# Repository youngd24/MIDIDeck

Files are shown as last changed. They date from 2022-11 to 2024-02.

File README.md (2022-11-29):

# The MIDI Deck

What is it? an Arduino Pro Micro MIDI controller, connected via USB, that can send MIDI messages to a host on button press. The idea is to automate apps on the host, in my primary use case, OBS. Press button, things happen.

The design is as dead simple as possible so it's easy to build, total cost is under $20 (likely less).

Full docs [here](https://youngd24.github.io/MIDIDeck/)

A YouTube video that describes this is [here](https://youtu.be/XT2bshyCDlI)

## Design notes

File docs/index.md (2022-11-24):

# MIDI Deck

What is it? an Arduino Pro Micro MIDI controller, connected via USB, that can send MIDI messages to a host on button press. The idea is to automate apps on the host, in my primary use case, OBS. Press button, things happen.

The design is as dead simple as possible so it's easy to build, total cost is under $20 (likely less).

MIDIDeck_Image

## Why?

There were 2 main drivers I had for building this, the first is when I'm recording for YouTube videos. I use OBS with several cameras and other inputs and rather than flipping between them in editing I switch while recording. Why? I hate editing and this saves time there.

Second is for streaming, the keyboad combos I ended up using in OBS were awkward to use and I was always forgetting them. There's a reason the StreamDeck exists, this serves the same function.

## Goals

For the initial version, I had the following objectives:

* All command comms use MIDI (rather than HID)
* Prefer an Arduino platform
* Be as simple as possible to build
* Low cost
* Use PlatformIO to build

### MIDI

So why MIDI and not HID? Well, mainly because I have some other projects that I want to use MIDI on an Arduino for, this was the chance to have a super simple project to learn how to do it. My learning process tends to be additive and cumulative, I start with simple ideas, learn it thoroughly, then grow and learn more.

### Arduino

Why Arduino and not a, say, ESP32 or even a Raspberry Pi? The Pi could certainly do this but as of this writing, late 2022, they're still difficult to find and tend to be costly due to the [chip chortage](https://www.youtube.com/watch?v=vGjQcPUfBdM).

The specific Arduino I chose was the [Pro Micro](https://docs.arduino.cc/hardware/micro), it has sufficient pins and runs the ATmega32u4 processor with native USB support. It's that processor that enables the MIDI goal to be met. Note that this board appears to many things, including how you compile for it, as the Leonardo. From what I can tell this is simply a smaller profile of that board but has the same basic features and functionality.

### Simple to Build

I wanted this to be simple enough that anyone could make it, that meant keeping the hardware part to the absolute bare minimum. In this case it's just the chip and the buttons, nothing else. The internal pull-up resistors on the Arduino are used for the buttons and debouncing is done in the software. Future, or maybe alternate ones, in the future might have some of those bits, we'll see.

### Low Cost

I picked up the 3 Arduino boards off Amazon for less than 20 bucks, add in the buttons, the board and wire and you'll MAYBE hit 20 total. Big maybe.

### PlatformIO

I like using PlatformIO (pio) with Visual Studio Code (vscode), the goal was to keep doing that. I'm supplying pre-built firmware, but if you want to build from scratch:

* Install VSCode
* Install PlatformIO
* Git clone this repo
* Build & upload

The PlatformIO project includes the needed board (Arduino Leonardo) and the MIDIUSB library (version 1.0.5 at this time).

I believe the Arduino IDE could be used to build this code, I haven't tried it, you're on your own for that.

## Hardware

### Materials Needed

Acquire the following, there's not much needed:

* [Arduino Pro Micro](https://www.amazon.com/HiLetgo-Atmega32U4-Bootloadered-Development-Microcontroller/dp/B01MTU9GOB/)
* [Small breadboard](https://www.amazon.com/DEYUE-breadboard-Set-Prototype-Board/dp/B07LFD4LT6/)
* [6x6x9mm Momentary Push Buttons](https://www.amazon.com/dp/B07CGCPGPT)
* [Hook up wire](https://www.amazon.com/TUOFENG-Hookup-Wires-6-Different-Colored/dp/B07TX6BX47/)

### Wiring Diagram

Hook it all up as follows:

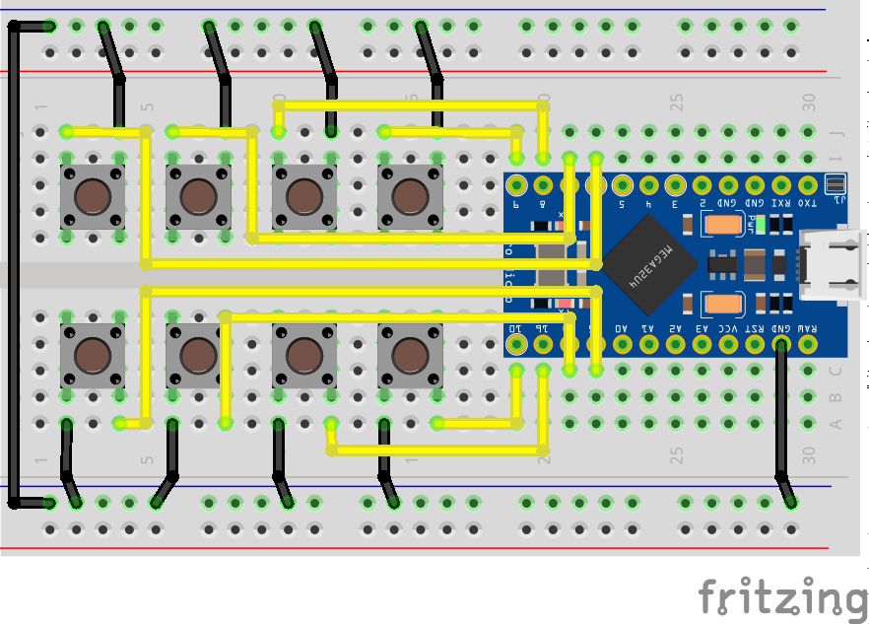
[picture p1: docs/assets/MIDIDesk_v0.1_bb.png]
MK1_Breadboard_Image


## OBS Setup

Once you're sure the hardware is working, and it sending the correct MIDI commands, download the [obs-midi-mg plugin](https://obsproject.com/forum/resources/obs-midi-mg.1570/). Note that I've only tested this on a Mac, not Windows or Linux, on those platforms you're on your own.

Once installed, launch OBS and bring up the plugin configuration menu. Add the 8 button, and using the "Listen Once" action press the button desired on the OBS Remote to bind the hardware button to the plugin. I changed the velocity to be any valid value, rather than what's in the code, it doesn't affect operation, all that's needed is the correct noteOn value.

My setup:

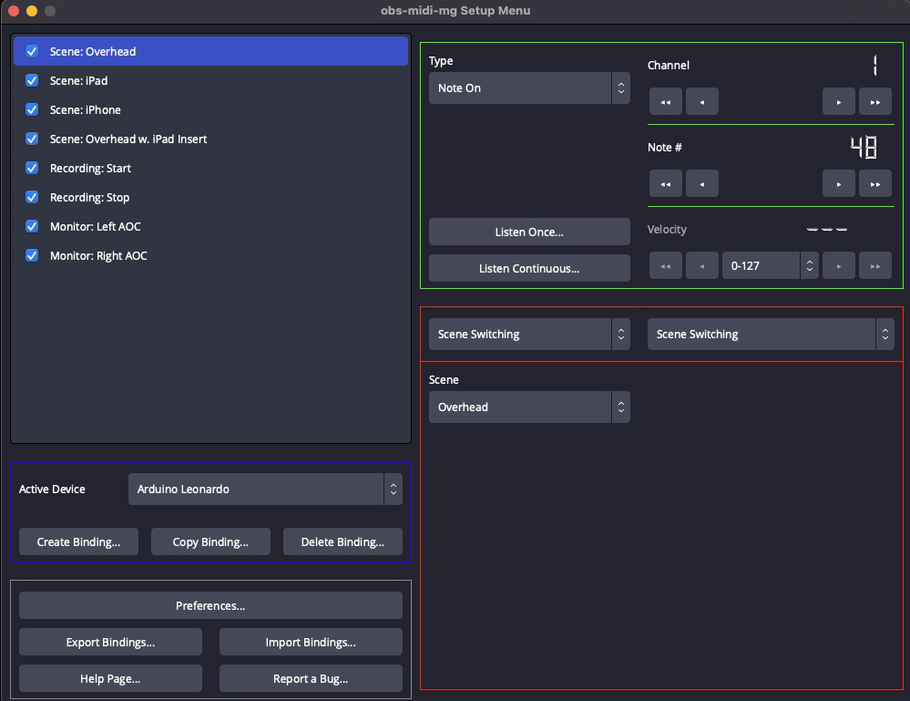
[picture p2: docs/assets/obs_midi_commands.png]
obs_midi_commands


## Companion Video

This page goes with my YouTube video on how to build and use this [here](https://www.youtube.com).

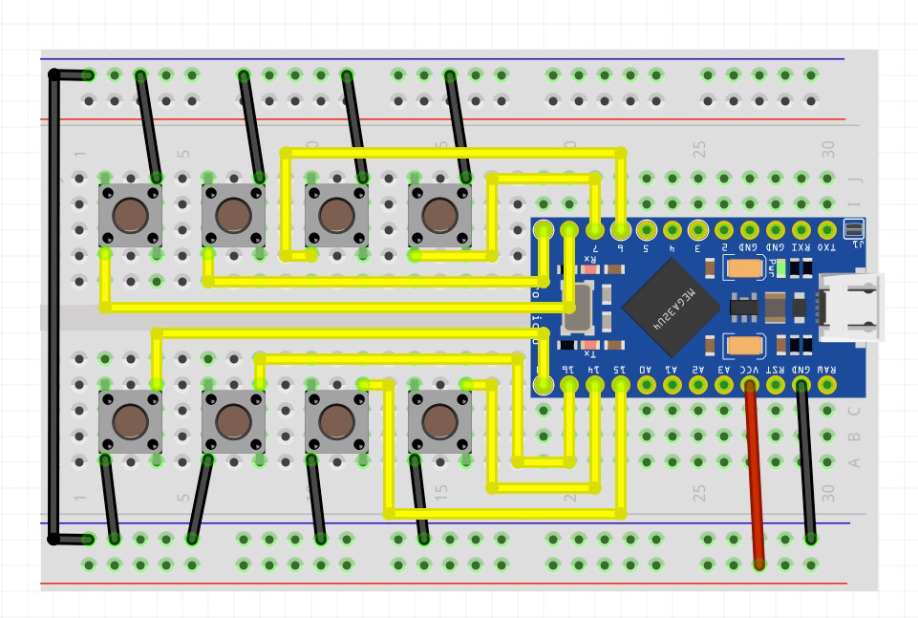
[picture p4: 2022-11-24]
docs/assets/breadboard_mk1.png

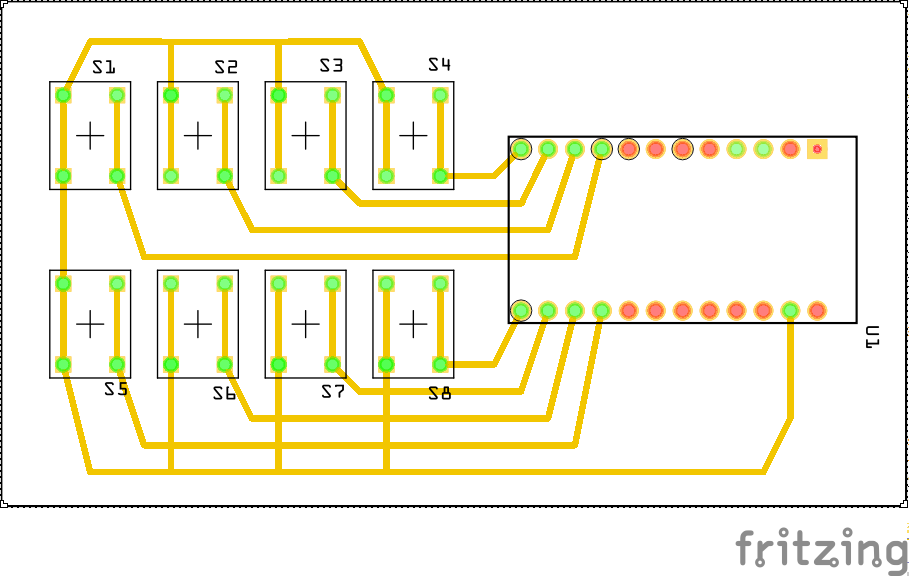
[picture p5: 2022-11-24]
docs/assets/MIDIDesk_v0.1_pcb.png

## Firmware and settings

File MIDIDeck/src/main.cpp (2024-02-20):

/******************************************************************************
 * 
 * Adruino Pro Micro MIDI Controller
 *
 * (C) 2022-2024 Darren Young [youngd24@gmail.com]
 * 
 * https://github.com/youngd24/MIDIDeck
 * 
 ******************************************************************************
 * 
 * CHANGELOG:
 * 
 * 19-Feb-2024
 * -----------
 *   - Adjusted for XL 12 button version
 *   - Increased delay to 250 (made it a const)
 *
 ******************************************************************************
 *
 * TODO:
 * 
 * Refactor all chunks of 1-8 stuff
 * Change delay to be a constant or #define
 * Add dev and release envs
 * Move debug prints to only happen in the dev env
 * Move functions into their own cpp file
 * Refactor main loop to act on an array of buttons (access by index)
 * Test removing pitchToNote.h
 * 
 *****************************************************************************/

// ----------------------------------------------------------------------------
// Program configuration
// ----------------------------------------------------------------------------

// System includes
#include <Arduino.h>

// Local/internal includes
#include "MIDIUSB.h"
#include "pitchToNote.h"

// Button Arduino pin assignments, based on what you did on the hardware
// On the prototype board these are laid out as:
//   row[0] = 1,2,3,4,5,6
//   row[1] = 7,8,9,10,11,12
const int button1pin = 4;
const int button2pin = 5;
const int button3pin = 6;
const int button4pin = 7;
const int button5pin = 8;
const int button6pin = 9;
const int button7pin = 10;
const int button8pin = 16;
const int button9pin = 14;
const int button10pin = 15;
const int button11pin = 18;
const int button12pin = 19;


// Button state tracking
int button1state;
int button2state;
int button3state;
int button4state;
int button5state;
int button6state;
int button7state;
int button8state;
int button9state;
int button10state;
int button11state;
int button12state;

// Vars
const int DELAY = 250;


// ----------------------------------------------------------------------------
// Functions
// ----------------------------------------------------------------------------

// ****************************************************************************
// NAME        : noteOn
// DESCRIPTION : Send MIDI note on message
// ARGUMENTS   : byte channel (1-16)
//             : byte pitch (note number)
//             : byte velocity (1-127)
// RETURN      : void
// STATUS      : Stable
// NOTES       : None
// ****************************************************************************
void noteOn(byte channel, byte pitch, byte velocity) {

  // First parameter is the event type (0x09 = note on, 0x08 = note off).
  // Second parameter is note-on/note-off, combined with the channel.
  // Channel can be anything between 0-15. Typically reported to the user as 1-16.
  // Third parameter is the note number (48 = middle C).
  // Fourth parameter is the velocity (64 = normal, 127 = fastest).
  midiEventPacket_t noteOn = {0x09, 0x90 | channel, pitch, velocity};
  MidiUSB.sendMIDI(noteOn);
}

// ****************************************************************************
// NAME        : noteOdd
// DESCRIPTION : Send MIDI note off message
// ARGUMENTS   : byte channel (1-16)
//             : byte pitch (note number)
//             : byte velocity (1-127)
// RETURN      : void
// STATUS      : Stable
// NOTES       : None
// ****************************************************************************
void noteOff(byte channel, byte pitch, byte velocity) {

  // First parameter is the event type (0x09 = note on, 0x08 = note off).
  // Second parameter is note-on/note-off, combined with the channel.
  // Channel can be anything between 0-15. Typically reported to the user as 1-16.
  // Third parameter is the note number (48 = middle C).
  // Fourth parameter is the velocity (64 = normal, 127 = fastest).
  midiEventPacket_t noteOff = {0x08, 0x80 | channel, pitch, velocity};
  MidiUSB.sendMIDI(noteOff);
}

// ****************************************************************************
// NAME        : controlChange
// DESCRIPTION : Change sound control
// ARGUMENTS   : byte channel
//             : byte control
//             : byte value
// RETURN      : void
// STATUS      : Stable
// NOTES       : None
// ****************************************************************************
void controlChange(byte channel, byte control, byte value) {

  // First parameter is the event type (0x0B = control change).
  // Second parameter is the event type, combined with the channel.
  // Third parameter is the control number number (0-119).
  // Fourth parameter is the control value (0-127).
  midiEventPacket_t event = {0x0B, 0xB0 | channel, control, value};
  MidiUSB.sendMIDI(event);
}


// ----------------------------------------------------------------------------
// Setup
// ----------------------------------------------------------------------------
void setup() {

  // Serial port setup
  Serial.begin(115200);
  
  // Input pin setup
  pinMode(button1pin, INPUT_PULLUP); 
  pinMode(button2pin, INPUT_PULLUP);
  pinMode(button3pin, INPUT_PULLUP);
  pinMode(button4pin, INPUT_PULLUP);
  pinMode(button5pin, INPUT_PULLUP); 
  pinMode(button6pin, INPUT_PULLUP);
  pinMode(button7pin, INPUT_PULLUP);
  pinMode(button8pin, INPUT_PULLUP); 
  pinMode(button9pin, INPUT_PULLUP);  
  pinMode(button10pin, INPUT_PULLUP);  
  pinMode(button11pin, INPUT_PULLUP);  
  pinMode(button12pin, INPUT_PULLUP);  

}

// ----------------------------------------------------------------------------
// Main loop
// ----------------------------------------------------------------------------
void loop() {

  // button1 state read
  button1state = digitalRead(button1pin);
  button2state = digitalRead(button2pin);
  button3state = digitalRead(button3pin);
  button4state = digitalRead(button4pin);  
  button5state = digitalRead(button5pin);
  button6state = digitalRead(button6pin);
  button7state = digitalRead(button7pin);
  button8state = digitalRead(button8pin); 
  button9state = digitalRead(button9pin);  
  button10state = digitalRead(button10pin);  
  button11state = digitalRead(button11pin);  
  button12state = digitalRead(button12pin);  


  // Button 1
  if (button1state == LOW) {
    Serial.println("BTN1: PRESSED");
    Serial.println("Sending note on");
    noteOn(0, 48, 64);
    MidiUSB.flush();
    delay(DELAY);
  }

  // Button 2
  if (button2state == LOW) {
    Serial.println("BTN2: PRESSED");
    Serial.println("Sending note on");
    noteOn(0, 50, 64);
    MidiUSB.flush();
    delay(DELAY);
  }

  // Button 3
  if (button3state == LOW) {
    Serial.println("BTN3: PRESSED");
    Serial.println("Sending note on");
    noteOn(0, 52, 64);
    MidiUSB.flush();
    delay(DELAY);
  }

  // Button 4
  if (button4state == LOW) {
    Serial.println("BTN4: PRESSED");
    Serial.println("Sending note on");
    noteOn(0, 54, 64);
    MidiUSB.flush();
    delay(DELAY);
  }

  // Button 5
  if (button5state == LOW) {
    Serial.println("BTN5: PRESSED");
    Serial.println("Sending note on");
    noteOn(0, 56, 64);
    MidiUSB.flush();
    delay(DELAY);
  }

  // Button 6
  if (button6state == LOW) {
    Serial.println("BTN6: PRESSED");
    Serial.println("Sending note on");
    noteOn(0, 58, 64);
    MidiUSB.flush();
    delay(DELAY);
  }

  // Button 7
  if (button7state == LOW) {
    Serial.println("BTN7: PRESSED");
    Serial.println("Sending note on");
    noteOn(0, 60, 64);
    MidiUSB.flush();
    delay(DELAY);
  }

  // Button 8
  if (button8state == LOW) {
    Serial.println("BTN8: PRESSED");
    Serial.println("Sending note on");
    noteOn(0, 62, 64);
    MidiUSB.flush();
    delay(DELAY);
  } 

  // Button 9
  if (button9state == LOW) {
    Serial.println("BTN9: PRESSED");
    Serial.println("Sending note on");
    noteOn(0, 64, 64);
    MidiUSB.flush();
    delay(DELAY);
  }

  // Button 10
  if (button10state == LOW) {
    Serial.println("BTN10: PRESSED");
    Serial.println("Sending note on");
    noteOn(0, 66, 64);
    MidiUSB.flush();
    delay(DELAY);
  }

  // Button 11
  if (button11state == LOW) {
    Serial.println("BTN11: PRESSED");
    Serial.println("Sending note on");
    noteOn(0, 68, 64);
    MidiUSB.flush();
    delay(DELAY);
  }

  // Button 12
  if (button12state == LOW) {
    Serial.println("BTN12: PRESSED");
    Serial.println("Sending note on");
    noteOn(0, 70, 64);
    MidiUSB.flush();
    delay(DELAY);
  }
}

// never get here

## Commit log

2022-11-22 added Fritzing files
    [MIDIDesk_v0.1.fzz]
2022-11-23 initial rough prototype version, needs refactoring (tons)
2022-11-24 updated Fritzing drawings
    [MIDIDesk_v0.1.fzz]
2024-02-20 Adjustments for 12 button version
